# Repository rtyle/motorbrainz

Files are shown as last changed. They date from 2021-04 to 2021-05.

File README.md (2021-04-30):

# motorbrainz
PCB with ESP32 microcontroller (brainz) and L298 dual full bridge (motor) driver.

The ESP32 of the [TinyPICO NANO](https://unexpectedmaker.com/shop/tinypico-nano) can be programmed by a host over the USB connection.
The ESP32 can be debugged by a host over the JTAG connection which is compatible with an [esp-prog](https://www.digikey.com/en/products/detail/espressif-systems/ESP-PROG/10259352) board, or equivalent.

The esp-prog BOOT and RST will not work because the esp-prog programming interface is not used.
The esp-prog jumper settings will have no effect.

**Warning:** The motorbrainz board ties all external ground references (12V, USB and JTAG) to the same common ground.
External 12V power should come from an isolated power supply to allow this.
The host providing USB 5V power (directly) and JTAG power (indirectly, by way of the host's USB connection to the esp-prog) should reference a common ground.

motorbrainz 5V power can either come from its 12V source (indirectly, by way of its LDO voltage regulator) or USB (directly) by setting a jumper.

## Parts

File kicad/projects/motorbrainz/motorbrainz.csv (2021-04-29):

Reference | Value | Footprint | Datasheet | Manufacturer | Manufacturer Product Number | Vendor | Vendor Part Number | Vendor URL
C3 | 100nF | Capacitor_SMD:C_0603_1608Metric | https://api.kemet.com/component-edge/download/specsheet/C0603C104J3RAC7411.pdf | Kemet | C0603C104J3RAC7411 | Digi-Key | C0603C104J3RAC7411CT-ND | https://www.digikey.com/en/products/detail/kemet/C0603C104J3RAC7411/12701256
U4 | CDBA240LL-HF | ultralibrarian:CDBA240LL-HF | https://www.comchiptech.com/admin/files/product/CDBA240LL-HF%20RevD765674.pdf | Comchip Technology | CDBA240LL-HF | Digi-Key | 641-1698-1-ND | https://www.digikey.com/en/products/detail/comchip-technology/CDBA240LL-HF/3308134
U6 | CDBA240LL-HF | ultralibrarian:CDBA240LL-HF | https://www.comchiptech.com/admin/files/product/CDBA240LL-HF%20RevD765674.pdf | Comchip Technology | CDBA240LL-HF | Digi-Key | 641-1698-1-ND | https://www.digikey.com/en/products/detail/comchip-technology/CDBA240LL-HF/3308134
U8 | CDBA240LL-HF | ultralibrarian:CDBA240LL-HF | https://www.comchiptech.com/admin/files/product/CDBA240LL-HF%20RevD765674.pdf | Comchip Technology | CDBA240LL-HF | Digi-Key | 641-1698-1-ND | https://www.digikey.com/en/products/detail/comchip-technology/CDBA240LL-HF/3308134
U10 | CDBA240LL-HF | ultralibrarian:CDBA240LL-HF | https://www.comchiptech.com/admin/files/product/CDBA240LL-HF%20RevD765674.pdf | Comchip Technology | CDBA240LL-HF | Digi-Key | 641-1698-1-ND | https://www.digikey.com/en/products/detail/comchip-technology/CDBA240LL-HF/3308134
U2 | L298P | SOIC127P1420X360-20N | http://www.st.com/content/ccc/resource/technical/document/datasheet/82/cc/3f/39/0a/29/4d/f0/CD00000240.pdf/files/CD00000240.pdf/jcr:content/translations/en.CD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 | STMicroelectronics | L298P | Digi-Key | 497-1396-5-ND | https://www.digikey.com/en/products/detail/stmicroelectronics/L298P/585919
J5 | Screw_Terminal_01x02 | snapeda:CONN_282836-2 | https://www.te.com/commerce/DocumentDelivery/DDEController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 | TE Connectivity AMP Connectors | 282836-2 | Digi-Key | A98076-ND | https://www.digikey.com/en/products/detail/te-connectivity-amp-connectors/282836-2/1826939
J4 | Screw_Terminal_01x02 | snapeda:CONN_282836-2 | https://www.te.com/commerce/DocumentDelivery/DDEController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 | TE Connectivity AMP Connectors | 282836-2 | Digi-Key | A98076-ND | https://www.digikey.com/en/products/detail/te-connectivity-amp-connectors/282836-2/1826939
C2 | 10uF | Capacitor_SMD:C_1206_3216Metric | https://api.kemet.com/component-edge/download/datasheet/C1206C106J3RACAUTO.pdf | Kemet | C1206C106J3RACAUTO | Digi-Key | 399-15734-1-ND | https://www.digikey.com/en/products/detail/kemet/C1206C106J3RACAUTO/7427564
C1 | 100nF | Capacitor_SMD:C_0603_1608Metric | https://api.kemet.com/component-edge/download/specsheet/C0603C104J3RAC7411.pdf | Kemet | C0603C104J3RAC7411 | Digi-Key | C0603C104J3RAC7411CT-ND | https://www.digikey.com/en/products/detail/kemet/C0603C104J3RAC7411/12701256
U11 | LD1117S50TR_SOT223 | Package_TO_SOT_SMD:SOT-223-3_TabPin2 | http://www.st.com/st-web-ui/static/active/en/resource/technical/document/datasheet/CD00000544.pdf | STMicroelectronics | LD1117S50TR | Digi-Key | LD1117S50TR | https://www.digikey.com/en/products/detail/stmicroelectronics/LD1117S50TR/1038360
J3 | Screw_Terminal_01x02 | snapeda:CONN_282836-2 | https://www.te.com/commerce/DocumentDelivery/DDEController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 | TE Connectivity AMP Connectors | 282836-2 | Digi-Key | A98076-ND | https://www.digikey.com/en/products/detail/te-connectivity-amp-connectors/282836-2/1826939
J6 | Conn_01x03_MountingPin | snapeda:SAMTEC_FTR-103-02-S-S | http://suddendocs.samtec.com/catalog_english/ftr_smt.pdf | Samtec Inc. | FTR-103-02-S-S | Digi-Key | SAM8907-ND | https://www.digikey.com/en/products/detail/samtec-inc/FTR-103-02-S-S/2651168
C4 | 100nF | Capacitor_SMD:C_0603_1608Metric | https://api.kemet.com/component-edge/download/specsheet/C0603C104J3RAC7411.pdf | Kemet | C0603C104J3RAC7411 | Digi-Key | C0603C104J3RAC7411CT-ND | https://www.digikey.com/en/products/detail/kemet/C0603C104J3RAC7411/12701256
R2 | 0.1 | Resistor_SMD:R_1206_3216Metric | https://industrial.panasonic.com/cdbs/www-data/pdf/RDN0000/AOA0000C313.pdf | Panasonic Electronic Components | ERJ-8BWFR100V | Digi-Key | P.10AUCT-ND | https://www.digikey.com/en/products/detail/panasonic-electronic-components/ERJ-8BWFR100V/1711656
R1 | 0.1 | Resistor_SMD:R_1206_3216Metric | https://industrial.panasonic.com/cdbs/www-data/pdf/RDN0000/AOA0000C313.pdf | Panasonic Electronic Components | ERJ-8BWFR100V | Digi-Key | P.10AUCT-ND | https://www.digikey.com/en/products/detail/panasonic-electronic-components/ERJ-8BWFR100V/1711656
U1 | tinyPICO_Nano | tinypico-hardware:TinyPICO_Nano | https://www.tinypico.com/tinypico-nano | UnexpectedMaker | Tiny-PICO_Nano | UnexpectedMaker | TinyPICO NANO | https://unexpectedmaker.com/shop/tinypico-nano
C5 | 47uF | Capacitor_SMD:C_2220_5650Metric | https://product.tdk.com/info/en/catalog/spec/mlccspec_automotive_general_en.pdf?ref_disty=digikey | TDK Corporation | CGA9N3X7R1E476M230KB | Digi-Key | 445-174773-1-ND | https://www.digikey.com/en/products/detail/tdk-corporation/CGA9N3X7R1E476M230KB/6556456
U9 | CDBA240LL-HF | ultralibrarian:CDBA240LL-HF | https://www.comchiptech.com/admin/files/product/CDBA240LL-HF%20RevD765674.pdf | Comchip Technology | CDBA240LL-HF | Digi-Key | 641-1698-1-ND | https://www.digikey.com/en/products/detail/comchip-technology/CDBA240LL-HF/3308134
U7 | CDBA240LL-HF | ultralibrarian:CDBA240LL-HF | https://www.comchiptech.com/admin/files/product/CDBA240LL-HF%20RevD765674.pdf | Comchip Technology | CDBA240LL-HF | Digi-Key | 641-1698-1-ND | https://www.digikey.com/en/products/detail/comchip-technology/CDBA240LL-HF/3308134
U3 | CDBA240LL-HF | ultralibrarian:CDBA240LL-HF | https://www.comchiptech.com/admin/files/product/CDBA240LL-HF%20RevD765674.pdf | Comchip Technology | CDBA240LL-HF | Digi-Key | 641-1698-1-ND | https://www.digikey.com/en/products/detail/comchip-technology/CDBA240LL-HF/3308134
U5 | CDBA240LL-HF | ultralibrarian:CDBA240LL-HF | https://www.comchiptech.com/admin/files/product/CDBA240LL-HF%20RevD765674.pdf | Comchip Technology | CDBA240LL-HF | Digi-Key | 641-1698-1-ND | https://www.digikey.com/en/products/detail/comchip-technology/CDBA240LL-HF/3308134
R4 | 10k | Resistor_SMD:R_0603_1608Metric | https://www.vishay.com/docs/20067/rcahp.pdf | Vishay Dale | RCA060310K0FKEAHP | Digi-Key | 541-3246-1-ND | https://www.digikey.com/en/products/detail/vishay-dale/RCA060310K0FKEAHP/6561243
JP1 | SolderJumper_3_Open | Jumper:SolderJumper-3_P1.3mm_Open_Pad1.0x1.5mm | ~
JP2 | SolderJumper_3_Open | Jumper:SolderJumper-3_P1.3mm_Open_Pad1.0x1.5mm | ~
JP4 | SolderJumper_3_Open | Jumper:SolderJumper-3_P1.3mm_Open_Pad1.0x1.5mm | ~
R3 | 10k | Resistor_SMD:R_0603_1608Metric | https://www.vishay.com/docs/20067/rcahp.pdf | Vishay Dale | RCA060310K0FKEAHP | Digi-Key | 541-3246-1-ND | https://www.digikey.com/en/products/detail/vishay-dale/RCA060310K0FKEAHP/6561243
R6 | 10k | Resistor_SMD:R_0603_1608Metric | https://www.vishay.com/docs/20067/rcahp.pdf | Vishay Dale | RCA060310K0FKEAHP | Digi-Key | 541-3246-1-ND | https://www.digikey.com/en/products/detail/vishay-dale/RCA060310K0FKEAHP/6561243
R5 | 10k | Resistor_SMD:R_0603_1608Metric | https://www.vishay.com/docs/20067/rcahp.pdf | Vishay Dale | RCA060310K0FKEAHP | Digi-Key | 541-3246-1-ND | https://www.digikey.com/en/products/detail/vishay-dale/RCA060310K0FKEAHP/6561243
R8 | 10k | Resistor_SMD:R_0603_1608Metric | https://www.vishay.com/docs/20067/rcahp.pdf | Vishay Dale | RCA060310K0FKEAHP | Digi-Key | 541-3246-1-ND | https://www.digikey.com/en/products/detail/vishay-dale/RCA060310K0FKEAHP/6561243
R7 | 10k | Resistor_SMD:R_0603_1608Metric | https://www.vishay.com/docs/20067/rcahp.pdf | Vishay Dale | RCA060310K0FKEAHP | Digi-Key | 541-3246-1-ND | https://www.digikey.com/en/products/detail/vishay-dale/RCA060310K0FKEAHP/6561243
R10 | 10k | Resistor_SMD:R_0603_1608Metric | https://www.vishay.com/docs/20067/rcahp.pdf | Vishay Dale | RCA060310K0FKEAHP | Digi-Key | 541-3246-1-ND | https://www.digikey.com/en/products/detail/vishay-dale/RCA060310K0FKEAHP/6561243
R9 | 10k | Resistor_SMD:R_0603_1608Metric | https://www.vishay.com/docs/20067/rcahp.pdf | Vishay Dale | RCA060310K0FKEAHP | Digi-Key | 541-3246-1-ND | https://www.digikey.com/en/products/detail/vishay-dale/RCA060310K0FKEAHP/6561243
R12 | 10k | Resistor_SMD:R_0603_1608Metric | https://www.vishay.com/docs/20067/rcahp.pdf | Vishay Dale | RCA060310K0FKEAHP | Digi-Key | 541-3246-1-ND | https://www.digikey.com/en/products/detail/vishay-dale/RCA060310K0FKEAHP/6561243
R11 | 10k | Resistor_SMD:R_0603_1608Metric | https://www.vishay.com/docs/20067/rcahp.pdf | Vishay Dale | RCA060310K0FKEAHP | Digi-Key | 541-3246-1-ND | https://www.digikey.com/en/products/detail/vishay-dale/RCA060310K0FKEAHP/6561243
J7 | FTSH-105-01-S-DV-K | snapeda:SAMTEC-FTSH-105-01-X-DV | https://www.samtec.com/partnumber/ftsh-105-01-s-dv-k | Samtec Inc. | FTSH-105-01-S-DV-K | Digi-Key | FTSH-105-01-S-DV-K-ND | https://www.digikey.com/en/products/detail/samtec-inc/FTSH-105-01-S-DV-K/7433572
JP3 | SolderJumper_3_Open | Jumper:SolderJumper-3_P1.3mm_Open_Pad1.0x1.5mm | ~
JP5 | SolderJumper_3_Open | Jumper:SolderJumper-3_P1.3mm_Open_Pad1.0x1.5mm | ~
J1 | FTSH-105-01-S-DV-K | snapeda:SAMTEC-FTSH-105-01-X-DV | https://www.samtec.com/partnumber/ftsh-105-01-s-dv-k | Samtec Inc. | FTSH-105-01-S-DV-K | Digi-Key | FTSH-105-01-S-DV-K-ND | https://www.digikey.com/en/products/detail/samtec-inc/FTSH-105-01-S-DV-K/7433572
J2 | USB_B_Micro | Connector_USB:USB_Micro-B_Molex-105017-0001 | https://www.molex.com/pdm_docs/sd/1050170001_sd.pdf | Molex | 1050170001 | Digi-Key | WM1399CT-ND | https://www.digikey.com/en/products/detail/molex/1050170001/2350832

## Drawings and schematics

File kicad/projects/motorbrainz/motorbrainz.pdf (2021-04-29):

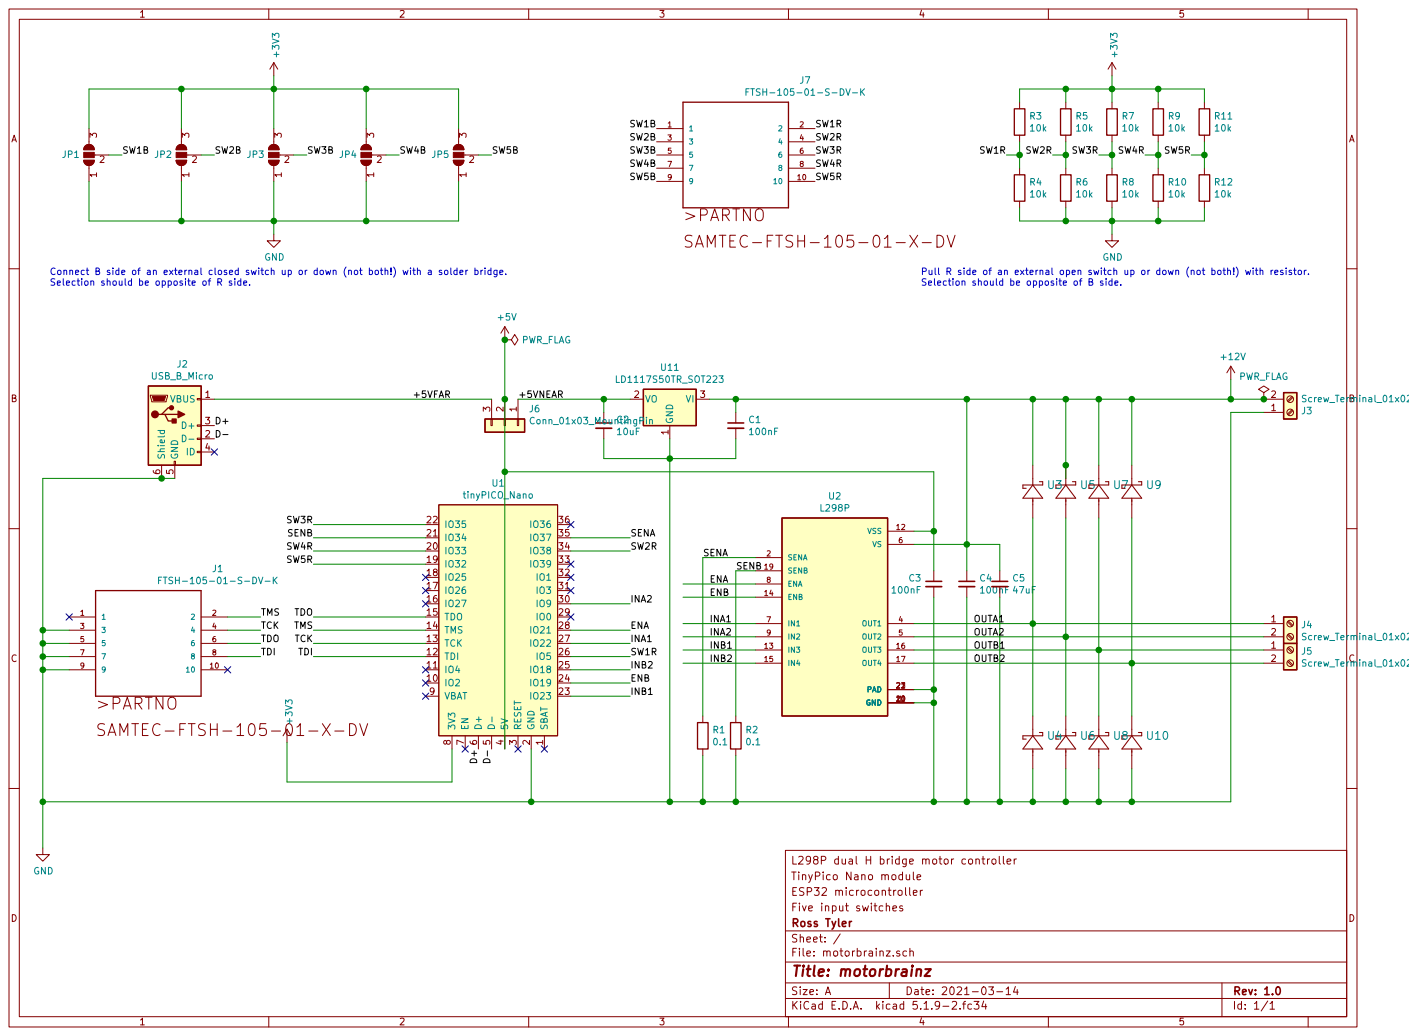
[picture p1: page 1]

SW2B Connect B side of an external closed switch up or down (not both!) with a solder bridge.

Pull R side of an external open switch up or down (not both!) with resistor.
Selection should be opposite of B side.

Selection should be opposite of R side.

IN1 7 ENA 8

INB1 ENB INA1 | IN3 13 ENB 14

INA2 | | 2

INB2 | | 2

L298P dual H bridge motor controller
Five input switches ESP32 microcontroller TinyPico Nano module

File: motorbrainz.sch Sheet: / Ross Tyler

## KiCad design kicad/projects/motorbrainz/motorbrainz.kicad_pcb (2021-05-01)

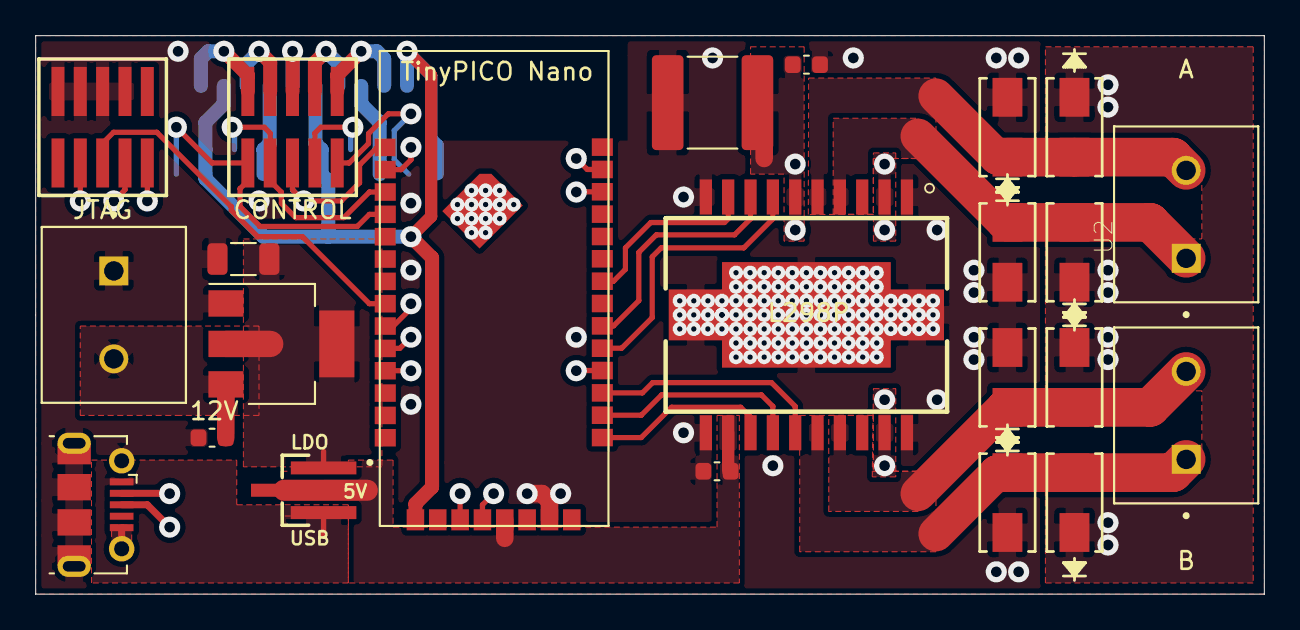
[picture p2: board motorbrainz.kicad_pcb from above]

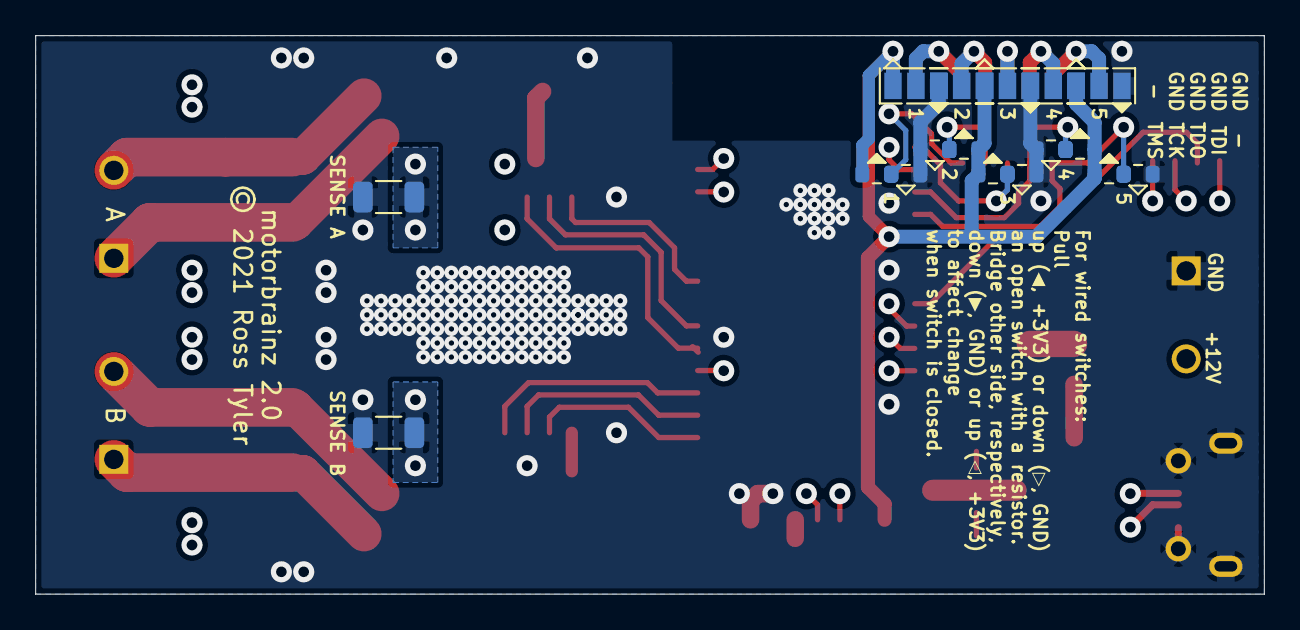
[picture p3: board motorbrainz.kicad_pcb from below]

Board: 4 copper layers, 69.9 x 31.8 mm, 40 parts (17 on the bottom side), 34 nets.

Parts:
C1, C3, C4: 100nF; C_0603_1608Metric
C2: 10uF; C_1206_3216Metric
C5: 47uF; C_2220_5650Metric
J1, J7: FTSH-105-01-S-DV-K; SAMTEC-FTSH-105-01-X-DV
J2: USB_B_Micro; USB_Micro-B_Molex-105017-0001
J3, J4, J5: Screw_Terminal_01x02; CONN_282836-2
J6: Conn_01x03_MountingPin; SAMTEC_FTR-103-02-S-S
JP1, JP2, JP3, JP4, JP5: SolderJumper_3_Open; SolderJumper-3_P1.3mm_Open_Pad1.0x1.5mm
R1, R2: 0.1; R_1206_3216Metric
R3, R4, R5, R6, R7, R8, R9, R10, R11, R12: 10k; R_0603_1608Metric
U1: tinyPICO_Nano; TinyPICO_Nano
U2: L298P; SOIC127P1420X360-20N
U3, U4, U5, U6, U7, U8, U9, U10: CDBA240LL-HF
U11: LD1117S50TR_SOT223; SOT-223-3_TabPin2

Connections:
+3V3: JP1.3, JP2.3, JP3.3, JP4.3, JP5.3, R3.1, R5.1, R7.1, R9.1, R11.1, U1.8
+5V: C3.1, J6.2, U1.4, U2.12
+12V: C1.1, C4.1, C5.1, J3.2, U2.6, U3.1, U5.1, U7.1, U9.1, U11.3
/+5VFAR: J2.1, J6.3
/+5VNEAR: C2.1, J6.1, U11.2
/D+: J2.3, U1.6
/D-: J2.2, U1.5
/ENA: U1.28, U2.8
/ENB: U1.24, U2.14
/INA1: U1.27, U2.7
/INA2: U1.30, U2.9
/INB1: U1.23, U2.13
/INB2: U1.25, U2.15
/OUTA1: J4.1, U2.4, U3.2, U4.1
/OUTA2: J4.2, U2.5, U5.2, U6.1
/OUTB1: J5.1, U2.16, U7.2, U8.1
/OUTB2: J5.2, U2.17, U9.2, U10.1
/SENA: R1.1, U1.35, U2.2
/SENB: R2.1, U1.21, U2.19
/SW1B: J7.1, JP1.2
/SW1R: J7.2, R3.2, R4.1, U1.26
/SW2B: J7.3, JP2.2
/SW2R: J7.4, R5.2, R6.1, U1.34
/SW3B: J7.5, JP3.2
/SW3R: J7.6, R7.2, R8.1, U1.22
/SW4B: J7.7, JP4.2
/SW4R: J7.8, R9.2, R10.1, U1.20
/SW5B: J7.9, JP5.2
/SW5R: J7.10, R11.2, R12.1, U1.19
/TCK: J1.4, U1.13
/TDI: J1.8, U1.12
/TDO: J1.6, U1.15
/TMS: J1.2, U1.14
GND: C1.2, C2.2, C3.2, C4.2, C5.2, J1.3, J1.5, J1.7, J1.9, J2.5, J2.6, J3.1, JP1.1, JP2.1, JP3.1, JP4.1, JP5.1, R1.2, R2.2, R4.2, R6.2, R8.2, R10.2, R12.2, U1.2, U2.1, U2.10, U2.11, U2.20, U2.21, U2.22, U2.23, U4.2, U6.2, U8.2, U10.2, U11.1

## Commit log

2021-04-29 2.0: replace ESP-PROG with USB connecter to use TinyPICO NANO USB to serial converter
    [motorbrainz-B_Cu.gbr, motorbrainz-B_Mask.gbr, motorbrainz-B_Paste.gbr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]
2021-04-29 export schematic as PDF
2021-05-01 thicken USB power traces
    [motorbrainz-B_Cu.gbr, motorbrainz-B_Mask.gbr, motorbrainz-B_Paste.gbr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]

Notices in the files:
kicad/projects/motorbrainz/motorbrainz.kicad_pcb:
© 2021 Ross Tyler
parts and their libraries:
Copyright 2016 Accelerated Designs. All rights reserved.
